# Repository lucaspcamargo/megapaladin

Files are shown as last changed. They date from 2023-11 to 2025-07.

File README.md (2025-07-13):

# mega-paladin v3 (WIP)

This is a switchless region mod for the SEGA Mega Drive, and a bluetooth controller host and adapter, based on the Raspberry Pi Pico W.

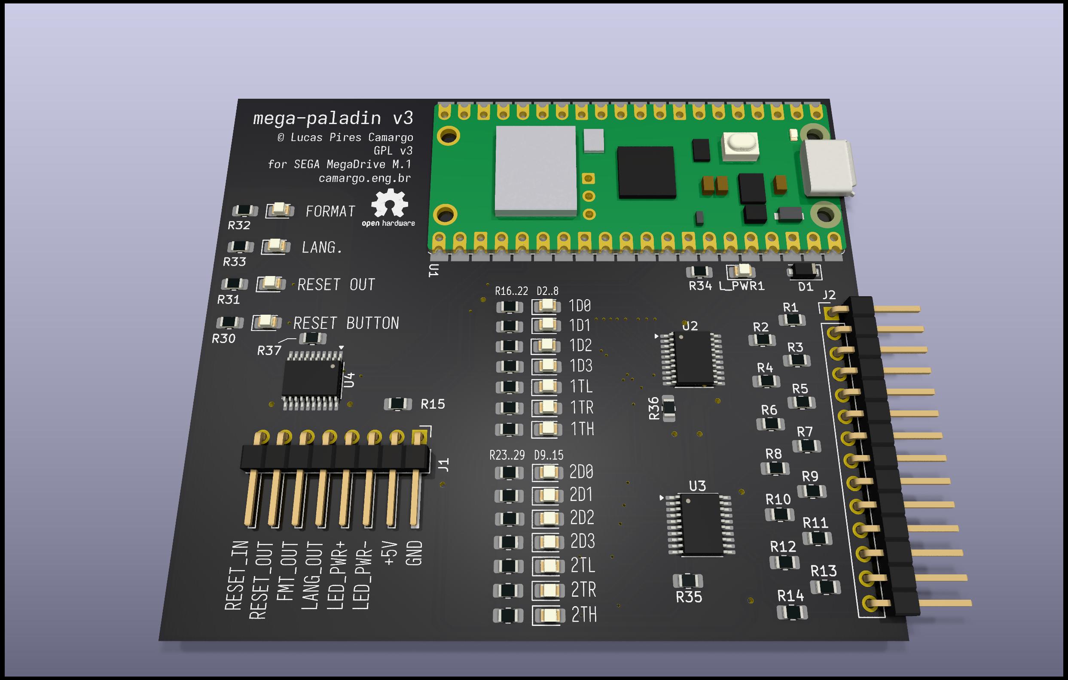
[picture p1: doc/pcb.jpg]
Picture of the mod after installation


For now the mod is quite simple, allowing to change the region of the console via a reset button bypass.
Hold reset for half a second and release, to change desired region. The power LED will blink once for US, twice for EU, and three times for JP. Then do a quick press of the reset button to apply the setting and reset the console. Easy peasy.

Since this mod maintains the original power LED and communicates the region setting via blinking, there's no need to change anything about the external appearance of the console. It should look exactly the same after installation.

WIP WIP WIP :: Wireless controller functionality is coming along, when using a Pico W. [Bluepad32](https://github.com/ricardoquesada/bluepad32) is working well as the joystick host solution, and it supports a wide variety of controllers.

PIO for proper controller port interfacing is on the way.

For more info on this mod, and the thought process, check out TODO, and maybe also [this post](https://camargo.eng.br/blog/2023/11-18-pal-megadrive.html) for the first version.

## Building

Install dependencies for `pico-sdk`. They were `cmake gcc-arm-none-eabi libnewlib-arm-none-eabi build-essential` at time of writing (on Arch).

```
$ git submodule update --init --recursive   # pico-sdk pulls in a lot of submodules, it's ok though
$ mkdir build && cd build
$ cmake ..
$ make
```

`megapaladin.uf2` should be in the `build` folder, ready to be flashed.

## Flashing

For the first flashing, proceed as if flashing any other Pico W device via UF2. Namely:

+ use uf2 file for initial installation
+ plug usb cable in computer keeping BOOTSEL button held
+ copy uf2 file into the disk device that appears
+ umount disk

Further flashing of modified firmware after initial setup can be done with:

```sh
picotool load -f -x build/megapaladin.elf
```

`picotool` may have to be installed separately.

Use `sudo` if there are permission errors reported (most likely missing `udev` rules, if on Linux). Check the `pico-sdk` and/or the `picotool` documentation for more info.

## Hardware Installation

An installation diagram is provided [here](doc/install%20plan.png). **(It needs updating for V3!)** It is for VA 6.5, check out other switchless mod install guides for other revisions/models.

## Warnings

### Connect the USB cable only when the Mega Drive is on

The 5V supply side should be protected from reverse-feeding the console via a diode. Also, the level shifters should maintain a high-impedance state on the 5V side when the console is off.

This was tested a couple of times. I cannot guarantee this behavior, though! Weird leakage could happen, potentially damaging your console. 

You have been warned.

## License

This project is licensed under the GPL v3. See the [LICENSE](LICENSE) file for more information.

## Troubleshooting

If you encounter issues with region switching or controller connectivity, try the following steps:

- Ensure that the reset button is being properly bypassed, and that the reset button output is cut off from feeding the IO controller's reset line.
- Double-check all wiring and solder joints.
- Ensure the Pico W is properly flashed and powered.
- Verify the reset button timing as described in the usage section.
- Consult the [Bluepad32 documentation](https://github.com/ricardoquesada/bluepad32) for controller pairing issues.

## Contributing

Contributions are welcome! Please open issues or submit pull requests for bug fixes, improvements, or new features.

## Contact

For questions or feedback, [open an issue on GitHub](https://github.com/lucaspcamargo/megapaladin/issues).

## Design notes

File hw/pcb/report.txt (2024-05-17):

Informação: Processando o símbolo 'R26:Resistor_SMD:R_0805_2012Metric_Pad1.20x1.40mm_HandSolder'.
Informação: Processando o símbolo 'R11:Resistor_SMD:R_0805_2012Metric_Pad1.20x1.40mm_HandSolder'.
Informação: Processando o símbolo 'R12:Resistor_SMD:R_0805_2012Metric_Pad1.20x1.40mm_HandSolder'.
Informação: Processando o símbolo 'R13:Resistor_SMD:R_0805_2012Metric_Pad1.20x1.40mm_HandSolder'.
Informação: Processando o símbolo 'R14:Resistor_SMD:R_0805_2012Metric_Pad1.20x1.40mm_HandSolder'.
Informação: Processando o símbolo 'R15:Resistor_SMD:R_0805_2012Metric_Pad1.20x1.40mm_HandSolder'.
Informação: Processando o símbolo 'R16:Resistor_SMD:R_0805_2012Metric_Pad1.20x1.40mm_HandSolder'.
Informação: Processando o símbolo 'R17:Resistor_SMD:R_0805_2012Metric_Pad1.20x1.40mm_HandSolder'.
Informação: Processando o símbolo 'R18:Resistor_SMD:R_0805_2012Metric_Pad1.20x1.40mm_HandSolder'.
Informação: Processando o símbolo 'R19:Resistor_SMD:R_0805_2012Metric_Pad1.20x1.40mm_HandSolder'.
Informação: Processando o símbolo 'R20:Resistor_SMD:R_0805_2012Metric_Pad1.20x1.40mm_HandSolder'.
Informação: Processando o símbolo 'R21:Resistor_SMD:R_0805_2012Metric_Pad1.20x1.40mm_HandSolder'.
Informação: Processando o símbolo 'D1:Diode_SMD:D_SOD-123F'.
Informação: Processando o símbolo 'R23:Resistor_SMD:R_0805_2012Metric_Pad1.20x1.40mm_HandSolder'.
Informação: Processando o símbolo 'R24:Resistor_SMD:R_0805_2012Metric_Pad1.20x1.40mm_HandSolder'.
Informação: Processando o símbolo 'R25:Resistor_SMD:R_0805_2012Metric_Pad1.20x1.40mm_HandSolder'.
Informação: Processando o símbolo 'R22:Resistor_SMD:R_0805_2012Metric_Pad1.20x1.40mm_HandSolder'.
Informação: Processando o símbolo 'R27:Resistor_SMD:R_0805_2012Metric_Pad1.20x1.40mm_HandSolder'.
Informação: Processando o símbolo 'R28:Resistor_SMD:R_0805_2012Metric_Pad1.20x1.40mm_HandSolder'.
Informação: Processando o símbolo 'R29:Resistor_SMD:R_0805_2012Metric_Pad1.20x1.40mm_HandSolder'.
Informação: Processando o símbolo 'R30:Resistor_SMD:R_0805_2012Metric_Pad1.20x1.40mm_HandSolder'.
Informação: Processando o símbolo 'R31:Resistor_SMD:R_0805_2012Metric_Pad1.20x1.40mm_HandSolder'.
Informação: Processando o símbolo 'R32:Resistor_SMD:R_0805_2012Metric_Pad1.20x1.40mm_HandSolder'.
Informação: Processando o símbolo 'R33:Resistor_SMD:R_0805_2012Metric_Pad1.20x1.40mm_HandSolder'.
Informação: Processando o símbolo 'R34:Resistor_SMD:R_0805_2012Metric_Pad1.20x1.40mm_HandSolder'.
Informação: Processando o símbolo 'U1:Module_RaspberryPi_Pico:RaspberryPi_Pico_W_SMD_MountingHoles_Castellated_HandSolder'.
Informação: Processando o símbolo 'U2:footprints:cheap_lvl_shifter_4ch'.
Informação: Processando o símbolo 'U3:footprints:cheap_lvl_shifter_4ch'.
Informação: Processando o símbolo 'U4:footprints:cheap_lvl_shifter_4ch'.
Informação: Processando o símbolo 'U5:footprints:cheap_lvl_shifter_4ch'.
Informação: Processando o símbolo 'U6:footprints:cheap_lvl_shifter_4ch'.
Informação: Processando o símbolo 'R9:Resistor_SMD:R_0805_2012Metric_Pad1.20x1.40mm_HandSolder'.
Informação: Processando o símbolo 'D2:LED_SMD:LED_0805_2012Metric_Pad1.15x1.40mm_HandSolder'.
Informação: Processando o símbolo 'D3:LED_SMD:LED_0805_2012Metric_Pad1.15x1.40mm_HandSolder'.
Informação: Processando o símbolo 'D4:LED_SMD:LED_0805_2012Metric_Pad1.15x1.40mm_HandSolder'.
Informação: Processando o símbolo 'D5:LED_SMD:LED_0805_2012Metric_Pad1.15x1.40mm_HandSolder'.
Informação: Processando o símbolo 'D6:LED_SMD:LED_0805_2012Metric_Pad1.15x1.40mm_HandSolder'.
Informação: Processando o símbolo 'D7:LED_SMD:LED_0805_2012Metric_Pad1.15x1.40mm_HandSolder'.
Informação: Processando o símbolo 'D8:LED_SMD:LED_0805_2012Metric_Pad1.15x1.40mm_HandSolder'.
Informação: Processando o símbolo 'D9:LED_SMD:LED_0805_2012Metric_Pad1.15x1.40mm_HandSolder'.
Informação: Processando o símbolo 'D10:LED_SMD:LED_0805_2012Metric_Pad1.15x1.40mm_HandSolder'.
Informação: Processando o símbolo 'D11:LED_SMD:LED_0805_2012Metric_Pad1.15x1.40mm_HandSolder'.
Informação: Processando o símbolo 'D12:LED_SMD:LED_0805_2012Metric_Pad1.15x1.40mm_HandSolder'.
Informação: Processando o símbolo 'D13:LED_SMD:LED_0805_2012Metric_Pad1.15x1.40mm_HandSolder'.
Informação: Processando o símbolo 'D14:LED_SMD:LED_0805_2012Metric_Pad1.15x1.40mm_HandSolder'.
Informação: Processando o símbolo 'D15:LED_SMD:LED_0805_2012Metric_Pad1.15x1.40mm_HandSolder'.
Informação: Processando o símbolo 'J1:Connector_PinHeader_2.54mm:PinHeader_1x08_P2.54mm_Horizontal'.
Informação: Processando o símbolo 'L_FMT_OUT1:LED_SMD:LED_0805_2012Metric_Pad1.15x1.40mm_HandSolder'.
Informação: Processando o símbolo 'R10:Resistor_SMD:R_0805_2012Metric_Pad1.20x1.40mm_HandSolder'.
Informação: Processando o símbolo 'R8:Resistor_SMD:R_0805_2012Metric_Pad1.20x1.40mm_HandSolder'.
Informação: Processando o símbolo 'R7:Resistor_SMD:R_0805_2012Metric_Pad1.20x1.40mm_HandSolder'.
Informação: Processando o símbolo 'R6:Resistor_SMD:R_0805_2012Metric_Pad1.20x1.40mm_HandSolder'.
Informação: Processando o símbolo 'R5:Resistor_SMD:R_0805_2012Metric_Pad1.20x1.40mm_HandSolder'.
Informação: Processando o símbolo 'R4:Resistor_SMD:R_0805_2012Metric_Pad1.20x1.40mm_HandSolder'.
Informação: Processando o símbolo 'R3:Resistor_SMD:R_0805_2012Metric_Pad1.20x1.40mm_HandSolder'.
Informação: Processando o símbolo 'R1:Resistor_SMD:R_0805_2012Metric_Pad1.20x1.40mm_HandSolder'.
Informação: Processando o símbolo 'J2:Connector_PinHeader_2.54mm:PinHeader_1x14_P2.54mm_Horizontal'.
Informação: Processando o símbolo 'L_LANG_OUT1:LED_SMD:LED_0805_2012Metric_Pad1.15x1.40mm_HandSolder'.
Informação: Processando o símbolo 'L_PWR1:LED_SMD:LED_0805_2012Metric_Pad1.15x1.40mm_HandSolder'.
Informação: Processando o símbolo 'L_R_IN1:LED_SMD:LED_0805_2012Metric_Pad1.15x1.40mm_HandSolder'.
Informação: Processando o símbolo 'L_R_OUT1:LED_SMD:LED_0805_2012Metric_Pad1.15x1.40mm_HandSolder'.
Informação: Processando o símbolo 'R2:Resistor_SMD:R_0805_2012Metric_Pad1.20x1.40mm_HandSolder'.
Reconecta U2 pino 1 de /IN_RESET_LV para /OUT_LANG_LV.
Reconecta U2 pino 7 de /OUT_LANG para /IN_RESET.
Reconecta U2 pino 8 de /OUT_FMT para /OUT_RESET.
Reconecta U2 pino 5 de /OUT_FMT_LV para /OUT_RESET_LV.
Reconecta U2 pino 2 de /OUT_RESET_LV para /OUT_FMT_LV.
Reconecta U2 pino 11 de /OUT_RESET para /OUT_FMT.
Reconecta U2 pino 12 de /IN_RESET para /OUT_LANG.
Reconecta U2 pino 6 de /OUT_LANG_LV para /IN_RESET_LV.
Atenção: Nenhuma rede foi encontrada para o componente U1 ilha TP5 (nenhum pino TP5 no símbolo).
Atenção: Nenhuma rede foi encontrada para o componente U1 ilha D2 (nenhum pino D2 no símbolo).
Atenção: Nenhuma rede foi encontrada para o componente U1 ilha TP5 (nenhum pino TP5 no símbolo).
Atenção: Nenhuma rede foi encontrada para o componente U1 ilha TP1 (nenhum pino TP1 no símbolo).
Atenção: Nenhuma rede foi encontrada para o componente U1 ilha D3 (nenhum pino D3 no símbolo).
Atenção: Nenhuma rede foi encontrada para o componente U1 ilha TP4 (nenhum pino TP4 no símbolo).
Atenção: Nenhuma rede foi encontrada para o componente U1 ilha TP6 (nenhum pino TP6 no símbolo).
Atenção: Nenhuma rede foi encontrada para o componente U1 ilha TP4 (nenhum pino TP4 no símbolo).
Atenção: Nenhuma rede foi encontrada para o componente U1 ilha D3 (nenhum pino D3 no símbolo).
Atenção: Nenhuma rede foi encontrada para o componente U1 ilha TP3 (nenhum pino TP3 no símbolo).
Atenção: Nenhuma rede foi encontrada para o componente U1 ilha D1 (nenhum pino D1 no símbolo).
Atenção: Nenhuma rede foi encontrada para o componente U1 ilha D1 (nenhum pino D1 no símbolo).
Atenção: Nenhuma rede foi encontrada para o componente U1 ilha 38 (nenhum pino 38 no símbolo).
Atenção: Nenhuma rede foi encontrada para o componente U1 ilha D2 (nenhum pino D2 no símbolo).
Atenção: Nenhuma rede foi encontrada para o componente U1 ilha TP6 (nenhum pino TP6 no símbolo).
Atenção: Nenhuma rede foi encontrada para o componente U1 ilha TP2 (nenhum pino TP2 no símbolo).

Informação: Total de avisos: 16, erros: 0.

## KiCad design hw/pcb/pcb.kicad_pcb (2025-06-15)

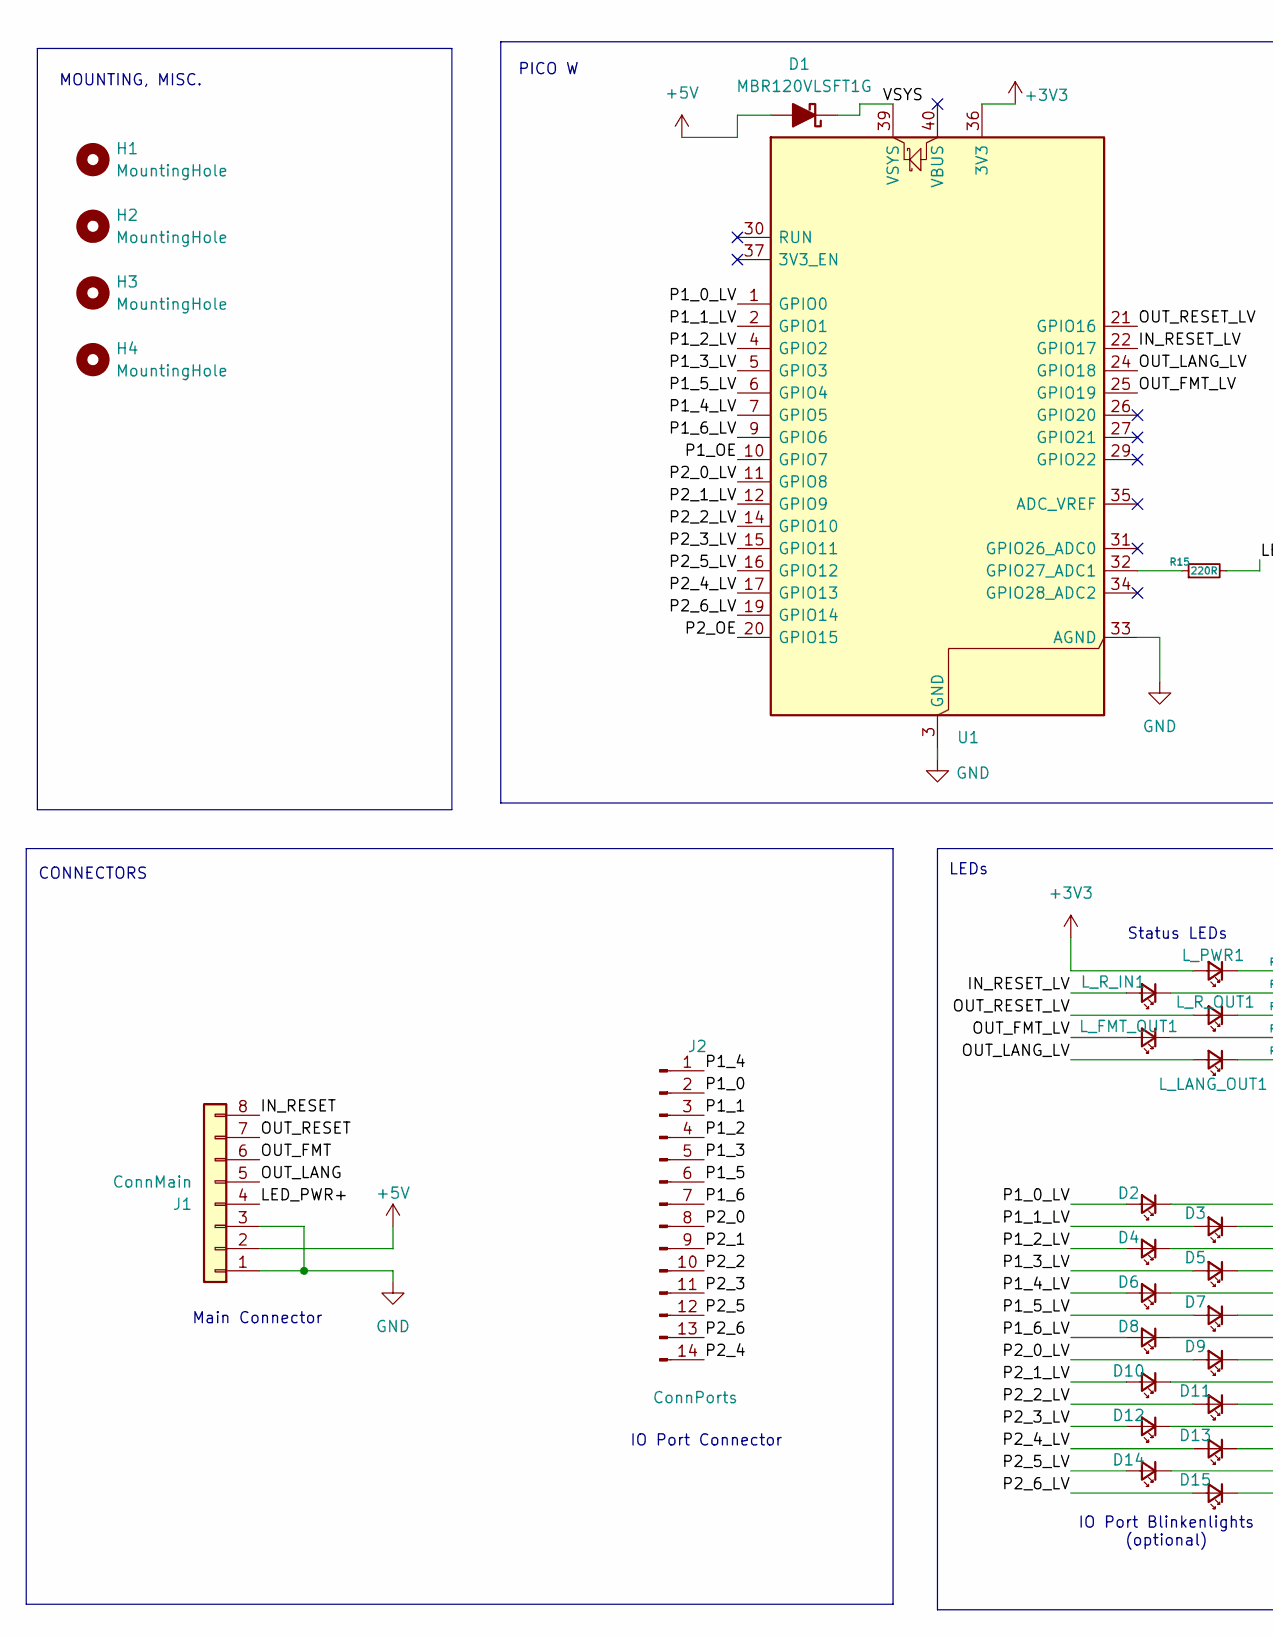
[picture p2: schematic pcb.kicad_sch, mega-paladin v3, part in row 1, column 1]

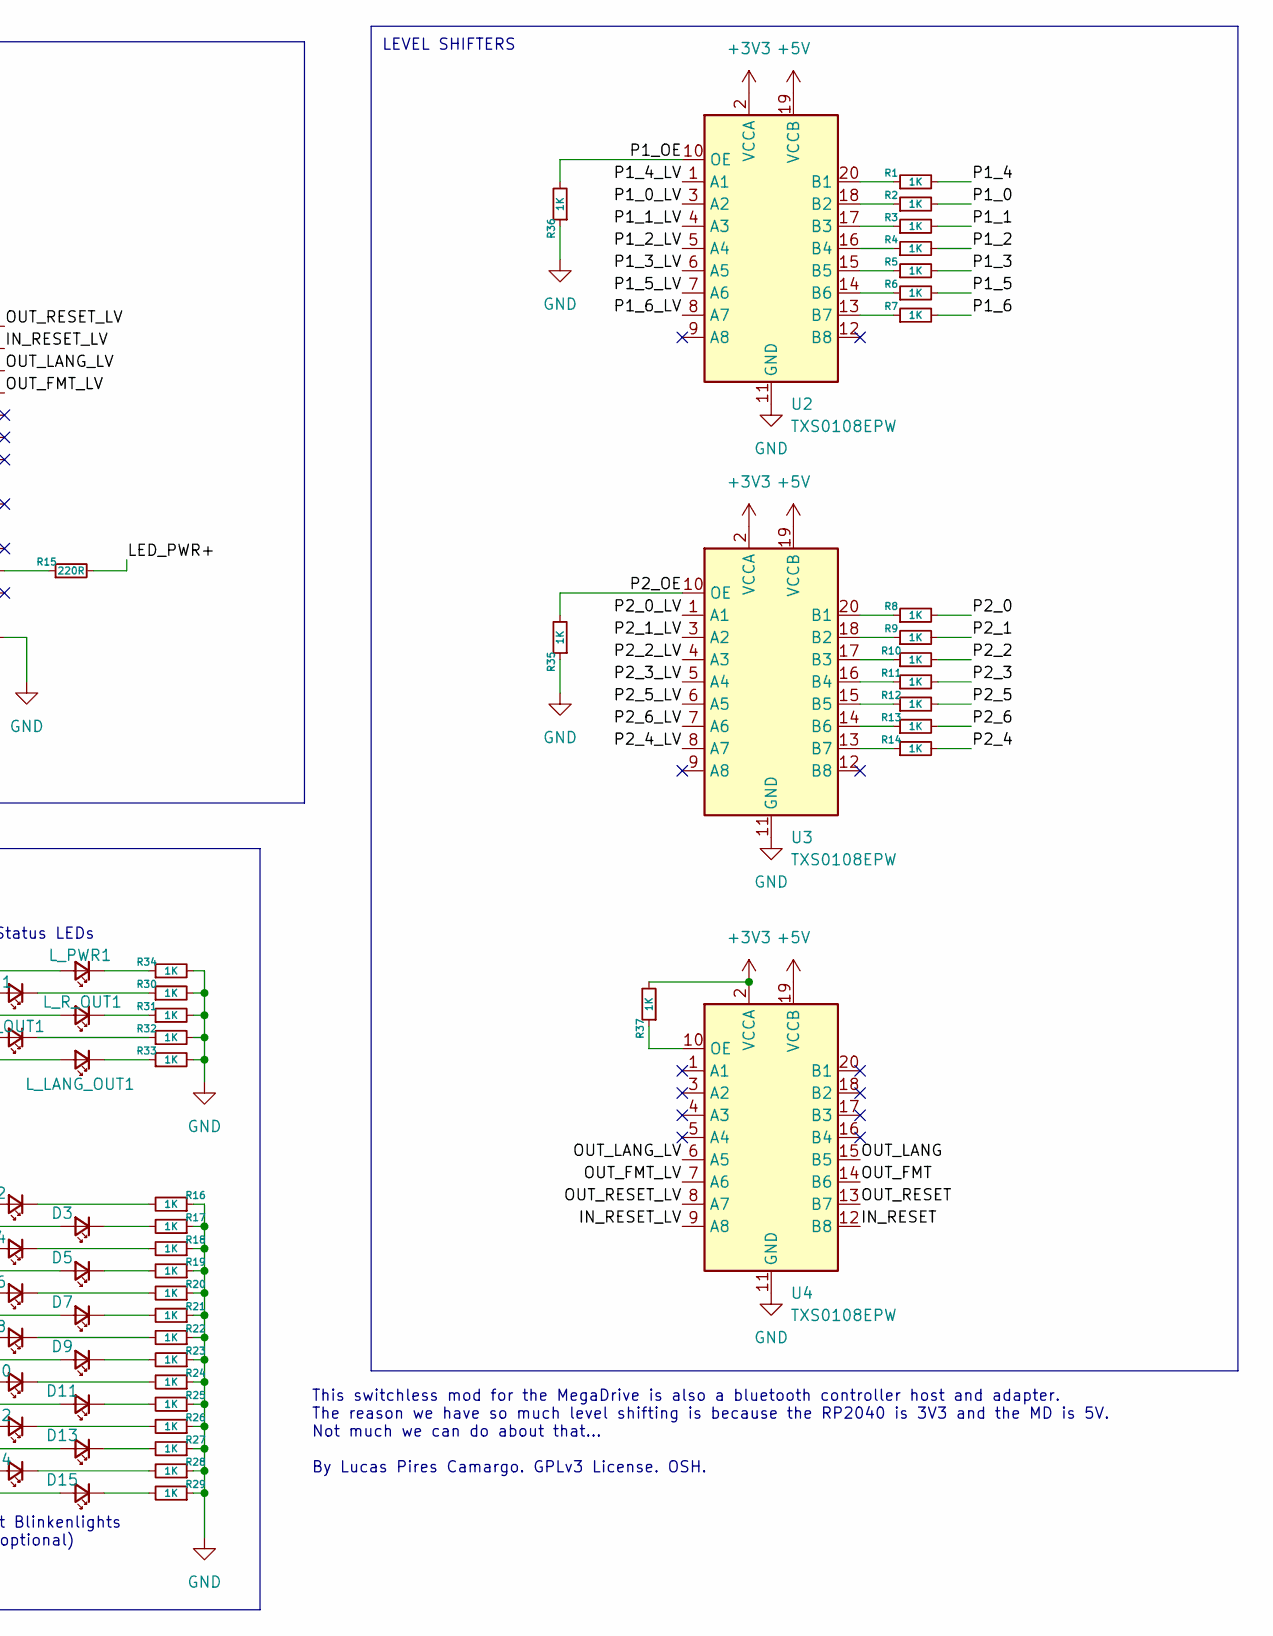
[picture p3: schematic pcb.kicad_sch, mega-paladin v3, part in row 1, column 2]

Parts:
D1: MBR120VLSFT1G; D_SOD-123F; LCSC PN C223608
D2, D4, D6, D8, D10, D12, D14: LED_0805_2012Metric_Pad1.15x1.40mm_HandSolder; LCSC PN C965813
D3, D5, D7, D9, D11, D13, D15: LED_Small; LED_0805_2012Metric_Pad1.15x1.40mm_HandSolder; LCSC PN C965813
H1, H2, H3, H4: MountingHole; MountingHole_2.2mm_M2_ISO14580
J1: ConnMain; PinHeader_1x08_P2.54mm_Horizontal; LCSC PN C492416
J2: ConnPorts; PinHeader_1x14_P2.54mm_Vertical; LCSC PN C18905874
L_FMT_OUT1: LED_0805_2012Metric_Pad1.15x1.40mm_HandSolder; LCSC PN C965817
L_LANG_OUT1: LED_Small; LED_0805_2012Metric_Pad1.15x1.40mm_HandSolder; LCSC PN C965817
L_PWR1: LED_Small; LED_0805_2012Metric_Pad1.15x1.40mm_HandSolder; LCSC PN C965812
L_R_IN1: LED_0805_2012Metric_Pad1.15x1.40mm_HandSolder; LCSC PN C965817
L_R_OUT1: LED_Small; LED_0805_2012Metric_Pad1.15x1.40mm_HandSolder; LCSC PN C965817
R1, R2, R3, R4, R5, R6, R7, R8, R9, R10, R11, R12, R13, R14, R16, R17, R18, R19, R20, R21, R22, R23, R24, R25, R26, R27, R28, R29, R30, R31, R32, R33, R34, R35, R36, R37: 1K; R_0805_2012Metric_Pad1.20x1.40mm_HandSolder; LCSC PN C17513
R15: 220R; R_0805_2012Metric_Pad1.20x1.40mm_HandSolder; LCSC PN C114519
U1: RaspberryPi_Pico_W_SMD_HandSolder; LCSC PN C7203003
U2, U3, U4: TXS0108EPW; TSSOP-20_4.4x6.5mm_P0.65mm; LCSC PN C17206

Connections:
+3V3: L_PWR1.2 (A), R37.2, U1.36 (3V3), U2.2 (VCCA), U3.2 (VCCA), U4.2 (VCCA)
+5V: D1.2 (A), J1.2, U2.19 (VCCB), U3.19 (VCCB), U4.19 (VCCB)
/IN_RESET: J1.8, U4.12 (B8)
/IN_RESET_LV: L_R_IN1.2 (A), U1.22 (GPIO17), U4.9 (A8)
/LED_PWR+: J1.4, R15.2
/OUT_FMT: J1.6, U4.14 (B6)
/OUT_FMT_LV: L_FMT_OUT1.2 (A), U1.25 (GPIO19), U4.7 (A6)
/OUT_LANG: J1.5, U4.15 (B5)
/OUT_LANG_LV: L_LANG_OUT1.2 (A), U1.24 (GPIO18), U4.6 (A5)
/OUT_RESET: J1.7, U4.13 (B7)
/OUT_RESET_LV: L_R_OUT1.2 (A), U1.21 (GPIO16), U4.8 (A7)
/P1_0: J2.2, R2.2
/P1_0_LV: D2.2 (A), U1.1 (GPIO0), U2.3 (A2)
/P1_1: J2.3, R3.2
/P1_1_LV: D3.2 (A), U1.2 (GPIO1), U2.4 (A3)
/P1_2: J2.4, R4.2
/P1_2_LV: D4.2 (A), U1.4 (GPIO2), U2.5 (A4)
/P1_3: J2.5, R5.2
/P1_3_LV: D5.2 (A), U1.5 (GPIO3), U2.6 (A5)
/P1_4: J2.1, R1.2
/P1_4_LV: D6.2 (A), U1.7 (GPIO5), U2.1 (A1)
/P1_5: J2.6, R6.2
/P1_5_LV: D7.2 (A), U1.6 (GPIO4), U2.7 (A6)
/P1_6: J2.7, R7.2
/P1_6_LV: D8.2 (A), U1.9 (GPIO6), U2.8 (A7)
/P1_OE: R36.2, U1.10 (GPIO7), U2.10 (OE)
/P2_0: J2.8, R8.2
/P2_0_LV: D9.2 (A), U1.11 (GPIO8), U3.1 (A1)
/P2_1: J2.9, R9.2
/P2_1_LV: D10.2 (A), U1.12 (GPIO9), U3.3 (A2)
/P2_2: J2.10, R10.2
/P2_2_LV: D11.2 (A), U1.14 (GPIO10), U3.4 (A3)
/P2_3: J2.11, R11.2
/P2_3_LV: D12.2 (A), U1.15 (GPIO11), U3.5 (A4)
/P2_4: J2.14, R14.2
/P2_4_LV: D13.2 (A), U1.17 (GPIO13), U3.8 (A7)
/P2_5: J2.12, R12.2
/P2_5_LV: D14.2 (A), U1.16 (GPIO12), U3.6 (A5)
/P2_6: J2.13, R13.2
/P2_6_LV: D15.2 (A), U1.19 (GPIO14), U3.7 (A6)
/P2_OE: R35.2, U1.20 (GPIO15), U3.10 (OE)
/VSYS: D1.1 (K), U1.39 (VSYS)
GND: J1.1, J1.3, R16.1, R17.1, R18.1, R19.1, R20.1, R21.1, R22.1, R23.1, R24.1, R25.1, R26.1, R27.1, R28.1, R29.1, R30.2, R31.2, R32.2, R33.2, R34.2, R35.1, R36.1, U1.3 (GND), U1.8 (GND), U1.13 (GND), U1.18 (GND), U1.23 (GND), U1.28 (GND), U1.33 (AGND), U1.38 (GND), U2.11 (GND), U3.11 (GND), U4.11 (GND)
unnamed: D2.1 (K), R16.2
unnamed: D3.1 (K), R17.2
unnamed: D4.1 (K), R18.2
unnamed: D5.1 (K), R19.2
unnamed: D6.1 (K), R20.2
unnamed: D7.1 (K), R21.2
unnamed: D8.1 (K), R22.2
unnamed: D9.1 (K), R23.2
unnamed: D10.1 (K), R24.2
unnamed: D11.1 (K), R25.2
unnamed: D12.1 (K), R26.2
unnamed: D13.1 (K), R27.2
unnamed: D14.1 (K), R28.2
unnamed: D15.1 (K), R29.2
unnamed: L_FMT_OUT1.1 (K), R32.1
unnamed: L_LANG_OUT1.1 (K), R33.1
unnamed: L_PWR1.1 (K), R34.1
unnamed: L_R_IN1.1 (K), R30.1
unnamed: L_R_OUT1.1 (K), R31.1
unnamed: R15.1, U1.32 (GPIO27_ADC1)
unnamed: R1.1, U2.20 (B1)
unnamed: R2.1, U2.18 (B2)
unnamed: R3.1, U2.17 (B3)
unnamed: R4.1, U2.16 (B4)
unnamed: R5.1, U2.15 (B5)
unnamed: R6.1, U2.14 (B6)
unnamed: R7.1, U2.13 (B7)
unnamed: R8.1, U3.20 (B1)
unnamed: R9.1, U3.18 (B2)
unnamed: R10.1, U3.17 (B3)
unnamed: R11.1, U3.16 (B4)
unnamed: R12.1, U3.15 (B5)
unnamed: R13.1, U3.14 (B6)
unnamed: R14.1, U3.13 (B7)
unnamed: R37.1, U4.10 (OE)

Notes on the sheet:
Main Connector
MOUNTING, MISC.
LEDs
IO Port Blinkenlights (optional)
Status LEDs
LEVEL SHIFTERS
PICO W
This switchless mod for the MegaDrive is also a bluetooth controller host and adapter. The reason we have so much level shifting is because the RP2040 is 3V3 and the MD is 5V. Not much we can do about that... By Lucas Pires Camargo. GPLv3 License. OSH.
CONNECTORS
IO Port Connector

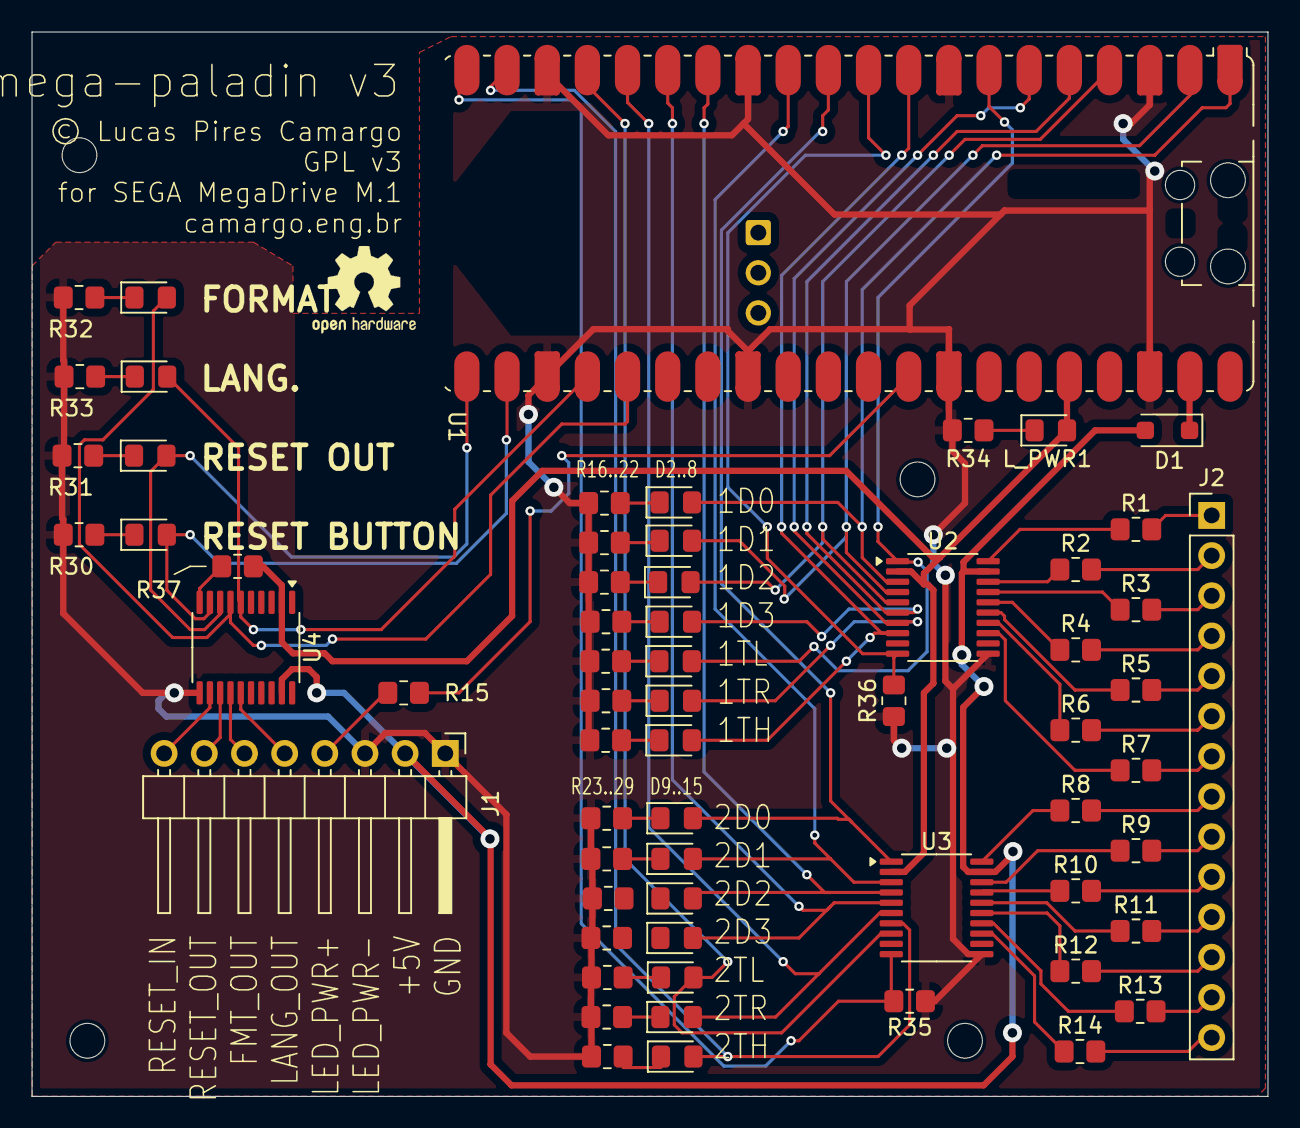
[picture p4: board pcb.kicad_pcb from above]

Board: 2 copper layers, 78.2 x 67.3 mm, 67 parts (0 on the bottom side), 78 nets.

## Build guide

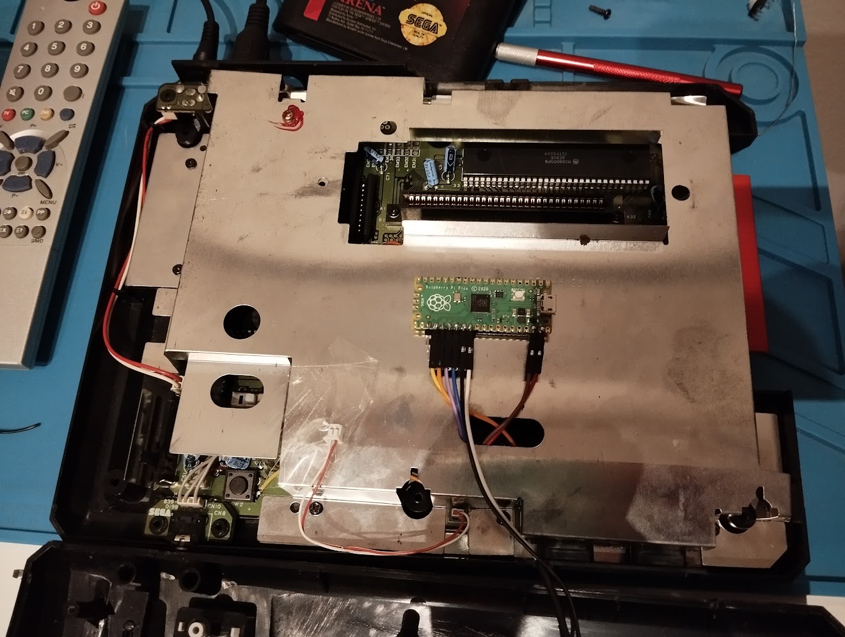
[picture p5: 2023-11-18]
doc/installed.jpg

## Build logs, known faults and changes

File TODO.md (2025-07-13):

# TODO 

+ [X] updated bluepad32 from develop, make it compile again
+ [X] figure out why Switch Pro controller crashes bluepad32!!!
+ [X] figure out why mouse events stop coming after a while...

+ [X] port to pico sdk, removing wifi
+ [X] use multiprocess module for processor communication
+ [X] move output control to core 1 completely
+ [X] add power led pwm and state machine
+ [X] enable bluetooth via btstack
+ [X] change core communications to queue_t
+ [ ] send events for mouse and keyboard to core 1
+ [ ] implement abstraction for io port
+ [ ] implement different state machines for different modes of the port
+ [ ] core 1 and 0 coordinate sync and controller assignment behavior, feedback
+ [ ] core 1 operates controller PIO accordingly
+ [X] HW: build first prototype (v1)
+ [X] HW: ~~rev. B:~~ v3:
    - [X] ~~fix dimensions of level shifter daughter boards~~ (not needed anymore, using proper shifter ICs)
    - [X] move Pi Pico USB port to board edge (duh!?)\

## BONUS

+ [ ] add serial port bluetooth, same functionality as usb serial port
+ [ ] integrate pico-flashloader
+ [ ] implement program update from bluetooth serial port
+ [ ] have some commands to enable and configure wifi
+ [ ] have some commands to initiate a telnet (maybe also ssh) session via wifi (use lwip and maybe wolfssh)

## for V3:

- [X] use same order of bits as mega drive does: -HRL3210
    + pin-wise, TR and TL are inverted. This is to match UART pins for smdt
     this will be handled transparently, internally
- [X] use contiguous pins for ports, enabling usage of PIO
- [ ] reimplement preipheral emulation with PIO
- [X] PCB: use level shifter ICs
- [ ] update docs (readme, new install guide pic.)

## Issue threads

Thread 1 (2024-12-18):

compiled

FranTerrassa, 2024-12-18:
Hi, I'm a noob, don't you have the code compiled yet?
thanks

lucaspcamargo, 2025-01-06:
[megapaladin-77b02a67c89d.zip](https://github.com/user-attachments/files/18318450/megapaladin-77b02a67c89d.zip)
In case you are still interested, this is the latest v2 version for the current hardware.

Note that what is supposed to be the main feature, wireless controllers, is still not implemented. A lot of it is there, but it was determined that doing it with pure GPIOs is not going to be fast enough, even with interrupts.

So a v3 is going to be needed, that puts all the port pins in contiguous pins so that PIO can be used for controller port interfacing instead...

As it is, v2 is a pretty good switchless region mod, and is useful if you want to monitor and debug the controller ports, but is not good for much else right now. I'd wait for v3 for the real deal. A lot of what is needed is already in place, we just need to be able to interface with the controller ports fast enough.

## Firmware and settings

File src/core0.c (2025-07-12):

#include "defs.h"
#include "support.h"
#include "bt_platform.h"

#include <stdio.h>
#include <string.h>
#include <malloc.h>
#include <pico/stdlib.h>
#include <pico/multicore.h>
#include <pico/flash.h>
#include <hardware/clocks.h>
#include <hardware/watchdog.h>
#include "hardware/vreg.h"

#include <btstack_run_loop.h>
#include <pico/cyw43_arch.h>
#include "sdkconfig.h"
#include "uni.h"
#ifndef CONFIG_BLUEPAD32_PLATFORM_CUSTOM
#error "Pico W must use BLUEPAD32_PLATFORM_CUSTOM"
#endif


btstack_timer_source_t main_timer;
char cmd_buf[CMD_BUF_SZ];
uint8_t cmd_buf_len;
bool usb_uart_ok = false;
bool syncing = false;

void core0_btstack_timer(btstack_timer_source_t *);
void core0_process_core1_cmd(const FIFOCmd repl);
void core0_process_serial_cmd();
void core0_status_print(enum Region curr_region, enum Region sel_region);
void core1_preinit();
void core1_main();


int main() // for core 0
{
    vreg_set_voltage(VREG_VOLTAGE_1_30);
    set_sys_clock_khz(PICO_FREQ_KHZ, false);

    core1_preinit();
    fifo_init();
    // as soon as possible, get code in core 1 running (control)
    if(!flash_safe_execute_core_init())
    {
        stdio_init_all();
        printf("Failed to intialize flash access control. Program halted.\n");
        for(;;)
            tight_loop_contents();
    }
    multicore_launch_core1(core1_main);
    
    // now setup core 0
    cmd_buf_len = 0;

    // setup usb uart
    uint64_t serial_setup_start = time_us_64();
    stdio_init_all();
    while ((time_us_64() - serial_setup_start < SERIAL_INIT_TIMEOUT_US) && !stdio_usb_connected())
        tight_loop_contents();

    // finishing touches
    temp_init();

    // now, the wireless part
    // initialize CYW43 driver architecture (will enable BT if/because CYW43_ENABLE_BLUETOOTH == 1)
    int bt_error = cyw43_arch_init();
    if(bt_error)
        return -1;

    // Must be called before uni_init()
    uni_platform_set_custom(bt_platform_get());

    // Initialize BP32
    uni_init(0, NULL);

    // add application callback to run loop
    memset(&main_timer, 0x00, sizeof(btstack_timer_source_t));
    main_timer.process = &core0_btstack_timer;
    btstack_run_loop_set_timer(&main_timer, CORE0_MAIN_TIMER_INTERVAL);
    btstack_run_loop_add_timer(&main_timer);

    // Does not return.
    btstack_run_loop_execute();
    
    return 0;
}


void core0_btstack_timer(btstack_timer_source_t *timer)
{
    // NOTE: whatever can be sent to core1 straight from bt_platform, we do it there for the lowest latency
    static bool initial_prompt = false;
    if(!initial_prompt)
    {
        putchar('>');
        putchar(' ');
        initial_prompt = true;
    }

    // process console commands
    int c;
    while((c = getchar_timeout_us(0)) != PICO_ERROR_TIMEOUT)
    {
        if(c == '\r' || c == '\n')
        {
            putchar('\r');
            putchar('\n');
            if(cmd_buf_len)
            {
                cmd_buf[cmd_buf_len] = '\0';
                core0_process_serial_cmd();
            }
            putchar('>');
            putchar(' ');
            cmd_buf_len = 0;
        }
        else if(cmd_buf_len == (CMD_BUF_SZ-1))
        {
            cmd_buf_len = 0;
        }
        else if(c > 0 && c < 256)
        {
            cmd_buf[cmd_buf_len] = (char) c;
            putchar((char)c);
            cmd_buf_len++;
        }
    }

    // process core1 commands
    FIFOCmd core1_cmd;
    while (fifo_pop(&core1_cmd))
        core0_process_core1_cmd(core1_cmd);

    // blink 
    static bool on = false;
    if(on)
    {
        cyw43_arch_gpio_put(CYW43_WL_GPIO_LED_PIN, 1);
    }
    else
    {
        cyw43_arch_gpio_put(CYW43_WL_GPIO_LED_PIN, 0);
    }
    on = !on;

    // reschedule
    btstack_run_loop_set_timer(timer, CORE0_MAIN_TIMER_INTERVAL);
    btstack_run_loop_add_timer(timer);
}

void core0_process_core1_cmd(const FIFOCmd repl)
{
    switch (repl.opcode)
    {
    case FC_STATUS_REPL:
        core0_status_print((enum Region)repl.data[0],(enum Region)repl.data[1]);
        printf("Port event counter at %d\n", (int)repl.data[2]);
        break;
    case FC_SYNC_START_REQ:
    {
        syncing = true;
        uni_bt_enable_new_connections_safe(syncing);
        FIFOCmd reply;
        reply.opcode = FC_SYNC_STATUS_REPL;
        reply.data[0] = 1;  // 1 means syncing
        fifo_push(&reply);
        break;
    }
    case FC_SYNC_STOP_REQ:
    {
        syncing = false;
        uni_bt_enable_new_connections_safe(syncing);
        FIFOCmd reply;
        reply.opcode = FC_SYNC_STATUS_REPL;
        reply.data[0] = 0;  // 0 means not syncing
        fifo_push(&reply);
        break;
    }
    case FC_LOG_NOTIFY:
    {
        char buf[MSG_LEN_MAX];
        if(fifo_str_pop(buf))
            printf("CORE1: %s\n", buf);
        break;
    }
    default:
        printf("Core 0: unknown opcode from core 1: %d\n", (int)repl.opcode);
    }
}

void core0_process_serial_cmd()
{
    if (!strcmp(cmd_buf, "status") || !strcmp(cmd_buf, "s"))
    {
        FIFOCmd c = {FC_STATUS_REQ, 0, 0, 0};
        fifo_push(&c);
    }
    else if (!strcmp(cmd_buf, "sync"))
    {
        syncing = !syncing;
        uni_bt_enable_new_connections_safe(syncing);
        FIFOCmd reply;
        reply.opcode = FC_SYNC_STATUS_REPL;
        reply.data[0] = syncing? 1 : 0;
        fifo_push(&reply);
        if(syncing)
            printf("Sync started.\n");
        else
            printf("Sync stopped.\n");
    }
    else if (!strcmp(cmd_buf, "reset"))
    {
        FIFOCmd c = {FC_RESET, 0, 0, 0};
        fifo_push(&c);
        printf("Applied region, and resetted console.\n");
    }
    else if (!strcmp(cmd_buf, "us"))
    {
        FIFOCmd c = {FC_REGION_SELECT, REGION_US, 0, 0};
        fifo_push(&c);
        printf("Selected US region\n");
    }
    else if (!strcmp(cmd_buf, "eu"))
    {
        FIFOCmd c = {FC_REGION_SELECT, REGION_EU, 0, 0};
        fifo_push(&c);
        printf("Selected EU region\n");
    }
    else if (!strcmp(cmd_buf, "jp"))
    {
        FIFOCmd c = {FC_REGION_SELECT, REGION_JP, 0, 0};
        fifo_push(&c);
        printf("Selected JP region\n");
    }
    else if (!strcmp(cmd_buf, "reboot"))
    {
        printf("Rebooting the megaPALadin and the console.\n");
        FIFOCmd c = {FC_REGION_SELECT, DEFAULT_REGION, 0, 0};
        fifo_push(&c);
        c.opcode = FC_RESET;
        c.data[0] = 0;
        fifo_push(&c);
        // wait for core 1 to reset, with some safety margin
        sleep_ms(RESET_DURATION_MS + (RESET_DURATION_MS/4));
        reboot();   // TODO this is panicking
    }
    else if ((!strcmp(cmd_buf, "help")) || (!strcmp(cmd_buf, "?")))
    {
        printf("Available commands: status, sync, reset, us, eu, jp, reboot, help, ?\n");
    }
    else
        printf("Unrecognized command.\nTry 'help' or '?'.\n");

    cmd_buf_len = 0;
}

void core0_status_print(enum Region curr_region, enum Region sel_region)
{
    printf("\mega-paladin v%d rev. %d\n", MP_VERSION, MP_REVISION);
    printf("Current region: %s\n", region_str(curr_region));
    printf("Selected region: %s\n", region_str(sel_region));
    struct mallinfo mi = mallinfo();
    printf("System Frequency: %.03f MHz\n", clock_get_hz(clk_sys) / 1000000.f);
    printf("Heap mem: %d free, %d total\n", mi.fordblks, mi.arena);
    printf("Core temperature: %2.1fC\n", temp_read());
    printf("Device dump:\n");
    uni_bt_dump_devices_safe();
    printf("\n> ");
}

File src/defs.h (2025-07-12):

#pragma once

#include <pico/types.h>

#define MP_VERSION 1
#define MP_REVISION 0

// CONFIGS
#define IS_PICO_W (PICO_BOARD == "pico_w")
#define PICO_FREQ_KHZ 133000

#define DEFAULT_REGION REGION_US
#define CMD_BUF_SZ 16   // normal command queue, one for each direction
#define MSG_BUF_SZ 16   // message queue for prints from core 1
#define MSG_LEN_MAX 64  // maximum size of core1 log string
#define CORE0_MAIN_TIMER_INTERVAL 50  // TODO define value. seems to be in millisseconds
#define JOY_MAX 2
#define DEBUG_BT_PLATFORM 0

#define BUTTON_DEBOUNCE_US 50000        // 0.05s
#define BUTTON_LONGPRESS_US 400000        // 0.4s
#define BUTTON_SYNCPRESS_US 2500000        // 2.5 s
#define BLINK_DURATION_US 75000         // 0.075s
#define BLINK_INTERVAL_US 150000        // 0.15s
#define SERIAL_INIT_TIMEOUT_US 1000000  // 1s
#define RESET_DURATION_MS 200           // 0.2s
#define FIFO_TIMEOUT_US 10              // 0.00001 s

#define PORT_CYCLE_US 5000              // 5 ms between joy read cycles (protocol resets)

#define PWM_FULLBRIGHT 0xfffe

#define PIN_IN_RESET 17
#define PIN_OUT_RESET 16
#define PIN_OUT_FMT 19
#define PIN_OUT_LANG 18
#define PIN_OUT_PWR_LED 27


typedef uint64_t ulong;

enum Region
{
  REGION_US,
  REGION_EU,
  REGION_JP,
  REGION_COUNT
} __attribute__ ((packed));

enum Language
{
  LANG_JP = 0,
  LANG_EN = 1  
} __attribute__ ((packed));

enum Format
{
  FMT_PAL = 0,
  FMT_NTSC = 1
} __attribute__ ((packed));

typedef struct FIFOCmd_t
{
  unsigned char opcode;
  unsigned char data[3];
} __attribute__ ((aligned (4))) FIFOCmd;

enum FIFOCmdOpcode
{
  FC_NOP = 0,
  
  FC_STATUS_REQ, // 0->1
  FC_STATUS_REPL, // 1->0

  FC_REGION_SELECT, // 0->1
  FC_REGION_COMMIT, // 0->1
  FC_RESET, // 0->1

  FC_SYNC_START_REQ,  // 1->0
  FC_SYNC_STOP_REQ,  // 1->0
  FC_SYNC_STATUS_REPL,  // 0->1, whether sync is in progress, can stop by itself

  FC_JOY_HOST_STATUS, // 0->1, update connected devices info
  FC_JOY_HOST_EVENT,  // 0->1, information concerning controllers

  FC_LOG_NOTIFY, // 1->0, asks to get a message from log queue and print it out
} __attribute__ ((packed));

enum FIFOCmdFlags
{
  // for FC_JOY_HOST_STATUS
  FC_F_JOY_STATUS_CONNECTED = 0x01,
  FC_F_JOY_STATUS_DISCONNECTED = 0x02,
  // bytes 1 and 2 are the joy type of connected controllers, or NONE
  // 22221111 44443333

  // for FC_JOY_HOST_EVENT
  // byte 0 carries flags and the controller index: IIIIFFFF
  FC_F_JOY_EVENT_CURR = 0x01,
  // bytes 1 and 2 carry controller or mouse data
  // joypad: SACBRLDU ----MXYZ
  // mouse:  SACBYYYY YYXXXXXX, LMB=A RMB=C MMB=B, numbers have a sign bit, no complement, minus zero means overflow  
} __attribute__ ((packed));

// Device types
#define DEVICE_TYPE_NONE      0x00
#define DEVICE_TYPE_JOY       0x01  
#define DEVICE_TYPE_MOUSE     0x02
#define DEVICE_TYPE_UNKNOWN   0x0F


// Button bits
// WE USE SGDK STANDARD AROUND THESE PARTS
#define BIT_BTN_UP       0x0001
#define BIT_BTN_DOWN     0x0002
#define BIT_BTN_LEFT     0x0004
#define BIT_BTN_RIGHT    0x0008
#define BIT_BTN_A        0x0040
#define BIT_BTN_B        0x0010
#define BIT_BTN_C        0x0020
#define BIT_BTN_START    0x0080
#define BIT_BTN_X        0x0400
#define BIT_BTN_Y        0x0200
#define BIT_BTN_Z        0x0100
#define BIT_BTN_MODE     0x0800
#define BIT_BTN_LMB      0x0040  // is A
#define BIT_BTN_MMB      0x0010  // is B
#define BIT_BTN_RMB      0x0020  // is C

#define BIT_BTN_COUNT    12

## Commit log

2023-11-18 added arduino sketch for arduino-pico
2023-11-18 first working version (simple switchless)\nstopped using platformio for now, using simple arduino-pico sketch
2023-11-21 halfway porting to pico-sdk and away from arduino-pico
2023-11-21 pico-sdk port progress
2023-11-22 compiling under pico sdk
2023-11-23 added multicore flash concurrency init, this fixed the crashes. cyw43 and core 1 coexist now
    [core0.c, core1.c]
2023-11-28 basic functionality reinstated, pico-sdk port of v1 is done
2023-12-11 fixed button debounce on release, led behavior, updated TODO
    [button.c, core1.c]
2024-04-01 updated bluepad32 version and made necessary changes, added old v1 version just in case
2024-05-17 added pcb project, updated readme
    [pcb-B_Cu.gbr, pcb-B_Mask.gbr, pcb-B_Paste.gbr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]
2024-06-30 general progress
    [pcb.kicad_pcb, pcb.kicad_sch]
2024-08-05 changed to use gpio irqs for fast response in port code, general changes
    [pcb.kicad_sch]
2025-06-14 [hw] initial v3 design, updated readme
    [pcb.kicad_pcb, pcb.kicad_sch, signals.ods]
2025-06-15 [hw] final tweaks for pcb, incl. fabrication files
    [pcb.kicad_pcb, pcb.kicad_sch]
2025-06-16 [hw] added note to schematic about TL and TR order
    [pcb.kicad_sch]
2025-07-08 [defs,doc] changed pin assignments to match v3 hw
    [signals.ods]
2025-07-12 [general] misc fixes and preparation for v3
    [core0.c, defs.h, ports.c]
2025-07-12 [general] updated TODO, pico-sdk version
2025-07-14 [fw] pio init fixes
    [core1.c, ports.c]

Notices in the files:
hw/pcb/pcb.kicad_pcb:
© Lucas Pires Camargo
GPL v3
